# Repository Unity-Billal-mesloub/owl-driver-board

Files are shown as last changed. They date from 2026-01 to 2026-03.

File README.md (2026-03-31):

4-output OWL Driver Board version 2.4

4-output OWL Driver Board version 2.4

16-output OWL Driver Board version 1.0

16-output OWL Driver Board version 1.0
 
16-output OWL Driver Board version 1.0

The OWL Driver Board is a solid-state relay HAT for the Raspberry Pi. It was
developed for use with the [Open Weed Locator](https://github.com/Unity-Agriculture/OpenWeedLocator) 
but is suitable for any high-power, industrial, automotive or agricultural application.

It allows a Raspberry Pi to drive either 4x or 16x 2A outputs in any 12V or 24V
system, with the solid state switching allowing PWM control, including for
dimming LED strips. Outputs can be placed in parallel for more power if needed.

It is able to tolerate high levels of electrical noise, reverse polarity, short
circuit conditions and over voltage. It also protects the Pi from all this
electrical nastiness and provides a filtered source of 5V @ 5A!

It's ideal for use safely driving LED strips, high power motors, relays and
solenoids from a Raspberry Pi.

The board aims to be difficult to misconfigure and hard to damage.
Self-resetting polyfuses on the input and outputs limit current, and
TVS+Schottky diodes provide reverse polarity protection, protection against
noise and inductive voltage spikes, and over-voltage protection. This
protection also extends to communication buses with the Raspberry Pi.

# Features

### Both models (4x and 16x output versions)

* Open Hardware, made in the UK: schematics and design files freely available.
* Working voltage 7-26V
* 4x or 16x fused outputs, each max. 2A, high-side switched
* 1x e-stop / global enable input
* Outputs can be driven in multiple ways, configurable by a header
* From Raspberry PI GPIOs
* Directly from external control, via wires to a header. Control inputs are tolerant up to 26V.
* Buck converter generates 5.1V @ 3A continuous / 5A burst to power the Raspberry Pi (Pi 5 compatible!)
* Input and outputs are fused, with protection against over-voltage, reverse polarity, and inductive spikes
* LED indication of blown fuses

### Additional features for the 4x output version only

* 1x fused input max. 7A
* Self-resetting input polyfuse
* Integrated PCA9685 PWM driver allows optional PWM control via I2C, compatible with Adafruit PCA9675 Python libraries
* Input and output connectors use high-quality Phoenix Contact screw terminals
* Version 2.4

### Additional features for the 16x output version only

* 3x fused inputs max. 10A each (connect all inputs in parallel for 30A total board input power)
* 10A mini-blade fuses on inputs
* Spare fuse holder
* Inputs and outputs use JST VH connectors
* Version 1.0

# Purchase a finished board

You can buy a finished board (4x or 16x output versions) via the following distributors:

 * [paradar.co.uk](https://paradar.co.uk/products/owl-driver-board-raspberry-pi-automotive-relay-hat)

# Changelog

## 16x v1.1

* Correctly connect the input connectors to the input fuses.
* Add 10k discharge resistors across each output, to reduce "ghost voltages"
  see when outputs are off, caused by leakage across the MOSFETs

## 16x v1.0

* Initial prototype of a 16-output version of the PCB. Note the Gerbers for
  this version have a bug - the input connectors are not attached to the fuse
  input, and a link must be manually soldered.

## 4x v2.5

* Add 10k discharge resistors across each output, to reduce "ghost voltages"
  see when outputs are off, caused by leakage across the MOSFETs
* Change screw terminals for Phoenix Contact part 1935161 (C3819953), replaces 1890963. #1935161 is 11mm in height (down from 13mm) which improves clearance
  in the enclosure.

## 4x v2.4

* Add an "output enable" terminal (J10) for use with an emergency stop switch.
  Outputs are enabled when the terminal is shorted; they are disabled when it
  is disconnected.

## 4x v2.3

* Improved Pi regulator efficiency (81% -> 87%) to reduce heat generated when
  driving a Raspberry Pi 5

## 4x v2.2

* Change out the switching buck regulator from a 2A max limit to a 5A model.
  Increase the regulation voltage from 5.0V -> 5.1V to drive a Raspberry Pi 5
  without undervoltage warnings.
* Add a LM73100 ideal diode on the Pi 5V output to ensure there is no backflow
  of current from the Pi into the board when powered off, and the Pi has a
  separate USB-C power supply.

## 4x v2.1

* Add a slot for the Raspberry Pi camera connector, to allow the ribbon cable
  to easily pass through the driver board.
* Remove stacking power connector to allow space for the cable slot. If
  stacking is required, board power inputs should be wired in parallel.
* Fix major error in v2.0 where MOSFET rotations were incorrect
* General manufacturability improvements (component polarity in silkscreen)

## 4x v2.0

* Significantly rework layout to allow space for instructions on the top. Move
  most components to the bottom layer.
* Change MOSFETs from TO-220 to a compact SMD footprint.
* Add indicator LED to each output and the power input.
* Switch to generic spring connectors that are PTH rather than SMD; the Wago
  SMD connectors did not hold up well in use.
* Change diodes from SMA to DO-123F to save space.
* Change most resistors from 0805 to 0603 to save space.

## 4x v1.0

Initial prototype.

# Schematic and layout

KiCanvas links:

 * [Schematic](https://kicanvas.org/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)
 * [Layout](https://kicanvas.org/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)

# License

This open hardware project is Copyright (c) 2022 Guy Coleman and Patrick Coleman, and is released under an MIT license.

# Stacking

The HATs may be stacked and controlled with the PCA9685 by selecting different
I2C addresses for each board in the stack. In this configuation, the input power
terminals should be wired in parallel. Ensure that the wires used are rated for
sufficient current.

When stacked and in GPIO mode, turning on output #1 from the Raspberry Pi will
turn on all #1 outputs in the stack.

For individual control of all outputs in the stack
1. Set jumpers on header J6 to control outputs via the PCA9685 (the "PWM" setting).
1. Set SW1 to select a different address for each board in the stack.
1. Use the Adafruit PCA9685 Python library on the Raspberry Pi to communicate
   with each board via the chosen I2C addresses and control outputs
   individually.

Pi pin 22 (GPIO25) is connected to the PCA9685 Output Enable pin. Driving this
pin high on the Pi will disable all outputs in the stack (eg, for a software
emergency stop). It must be driven low for normal operation.

# Manufacturing

The project is set up for easy manufacture and assembly with JLCPCB, though it
will work with other suppliers too. All components should be available at
JLCPCB/LCSC and LCSC part numbers are included in KiKad fields for each part.

If you are having JLCPCB assemble the boards for you, you must manufacture in
panels (two boards per panel), as the board is too small for assembly alone. If
you will be assembling yourself, use pcb/gerbers/gb-owl-driver-board.zip for a single board.

1. Upload pcb/gerbers-panel-v2.4/gb-owl-driver-board-v2.4.zip to [JLCPCB's order tool](https://cart.jlcpcb.com/quote)
1. Configure the PCB manufacture settings to your requirements. Select "Confirm production file: Yes"
1. Select SMT assembly, and configure as follows: "Standard" assembly, "Both sides", and "Confirm production file". Click Confirm.
1. When prompted, upload the BOM (pcb/owl-driver-board_bom_jlc.csv) and Component Placement/CPL (pcb/owl-driver-board_cpl_jlc.csv) files.
1. Complete the SMT assembly wizard, aligning the parts to the board if necessary.

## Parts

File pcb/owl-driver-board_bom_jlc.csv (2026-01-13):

Comment | Designator | Footprint | LCSC Part Number
10uF | C1,C2,C3,C4,C5,C10,C11,C12,C14,C15,C16,C18,C19,C20 | C_1206_3216Metric_nosilk | C89835
0.1uF | C6,C7,C9,C17,C21,C25,C26,C27,C28,C29,C30 | C_0603_1608Metric_nosilk | C14663
100uF 6.3V | C13 | CP_EIA-3528-21_Kemet-B | C16133
10p | C22 | C_0805_2012Metric | C107107
2n | C23 | C_0603_1608Metric_nosilk | C1870141
10n | C24 | C_0603_1608Metric_nosilk | C77053
SZYY0805R | D1,D4,D5,D19,D20 | LED_0805_2012Metric | C434431
BZT585B13T-7 13V | D2,D3,D6,D17,D18 | D_SOD-523_silkpolarity | C460799
SMBJ26A | D7 | D_SMB_silkpolarity | C315992
DSK34 | D8,D9,D10,D11,D12,D13,D21,D22,D23,D24,D25,D26,D40 | D_SOD-123F_silkpolarity | C727076
SMBJ5.0A | D16 | D_SMB_silkpolarity | C83333
SZYY0805YG | D29,D30,D31,D37,D38,D41 | LED_0805_2012Metric | C434435
AZ23C3V3 | D32,D33,D34,D35 | SOT-23_nosilk | C968007
PDS1040L-13 | D36 | D_PowerDI-5 | C154714
BZT52C5V1T | D39,D42,D43,D44,D45 | D_SOD-523_silkpolarity | C2987034
2920L700/12 | F1 | Fuse_2920_7451Metric_nosilk | C207092
2920L200DR | F2,F3,F4,F5 | Fuse_2920_7451Metric_nosilk | C207087
CONN_04 | J1 | 1X04_NO_SILK | C358686
RASPBERRYPI-40-PIN-GPIO | J2 | Pin_Header_Straight_2x20 | C35165
1935161 | J3,J4,J5,J7,J8,J10 | TerminalBlock_Phoenix_PT-1,5-2-5.0-H_1x02_P5.00mm_Horizontal | C3819953
CONN_04X2 | J6 | 2X4 | C358693
PI 5V | J9 | PinHeader_1x02_P2.54mm_Vertical_nosilk | C358684
ENABLE | J11 | PinHeader_1x02_P2.54mm_Vertical_nosilk | C358684
10uH | L1 | L_10.4x10.4_H4.8 | C7461391
AGM60P85AP | Q1,Q2,Q3,Q6,Q7 | PDFN-8-3.3x3.3 | C17701049
2N7002 | Q4,Q5,Q8,Q9 | SOT-23_nosilk | C8545
1k | R1,R2,R3,R4,R5,R9,R10,R13,R14,R15,R16,R19,R20,R23,R39,R40,R48,R49 | R_0603_1608Metric | C21190
470 | R6,R7,R17,R18,R24,R25,R26,R27,R29,R30,R31,R38,R54,R55,R56,R57,R58 | R_0603_1608Metric | C25241
10k | R8,R11,R12,R21,R22,R28,R32,R33,R34,R35,R36,R37,R47,R50,R51,R52,R53,R59,R60,R61,R62 | R_0603_1608Metric | C15401
165k | R41 | R_0603_1608Metric | C22816
10.2k | R42 | R_0603_1608Metric | C22772
43k | R43 | R_0603_1608Metric | C23172
14k | R44 | R_0603_1608Metric | C22803
1.87k | R45 | R_0603_1608Metric | C22850
360k | R46 | R_0603_1608Metric | C23146
SW_Coded_SH-7050 | SW1 | Diptronics-Rotary-Switch-R7M3-16RA-V | C501563
TPS54531DDA | U1 | Texas_R-PDSO-G8_EP2.95x4.9mm_Mask2.4x3.1mm_ThermalVias | C50605
PCA9685PW | U2 | TSSOP-28_4.4x9.7mm_P0.65mm | C2678753
LM73100 | U3 | LM73100-QFN10 | C3210761
74LVC1G08 | U4,U5,U6,U7,U8 | SOT-353_SC-70-5 | C12512
XC6206P332MR | U9 | SOT-23 | C5148692

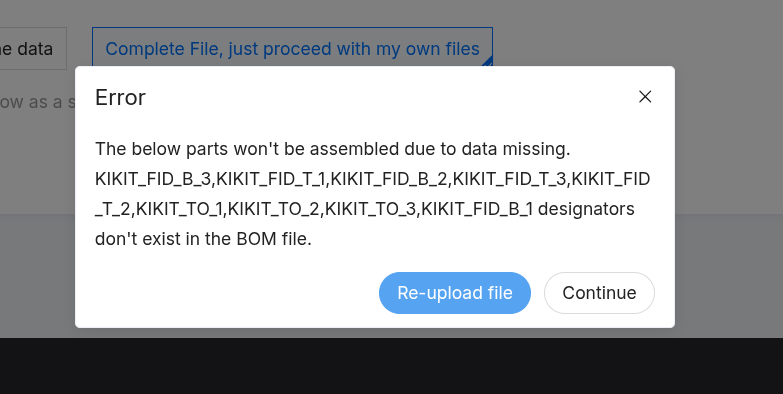
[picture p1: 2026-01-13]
doc/ordering-4-jlcpcb-ignore-this-error.png

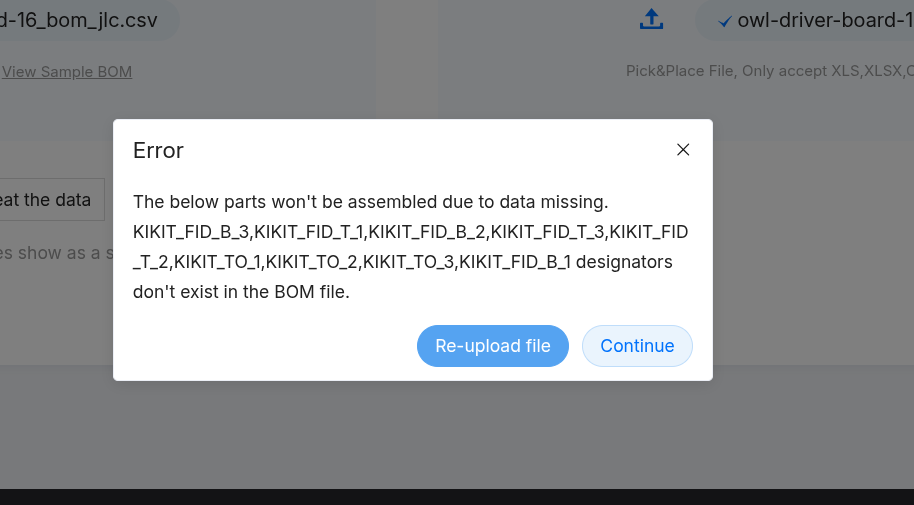
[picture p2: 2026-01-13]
doc/ordering-16-jlcpcb-ignore-this-error.png

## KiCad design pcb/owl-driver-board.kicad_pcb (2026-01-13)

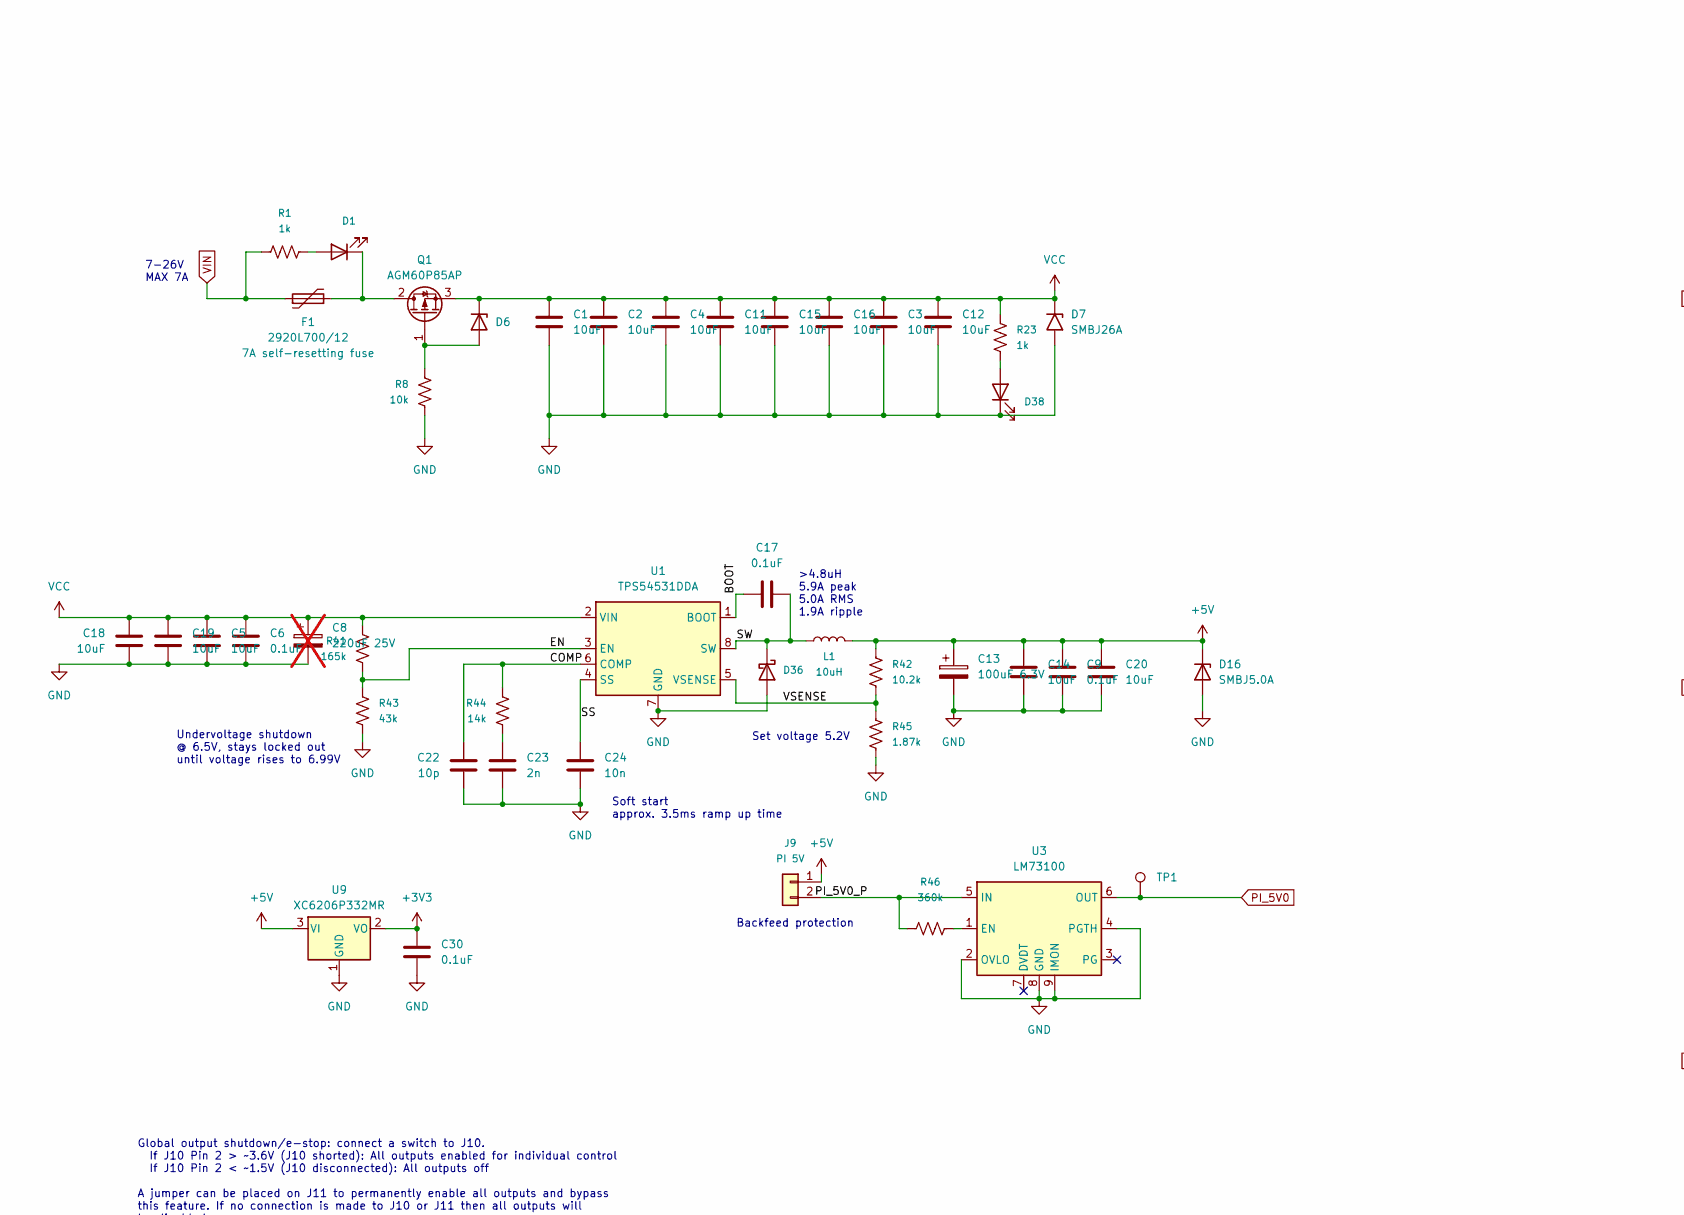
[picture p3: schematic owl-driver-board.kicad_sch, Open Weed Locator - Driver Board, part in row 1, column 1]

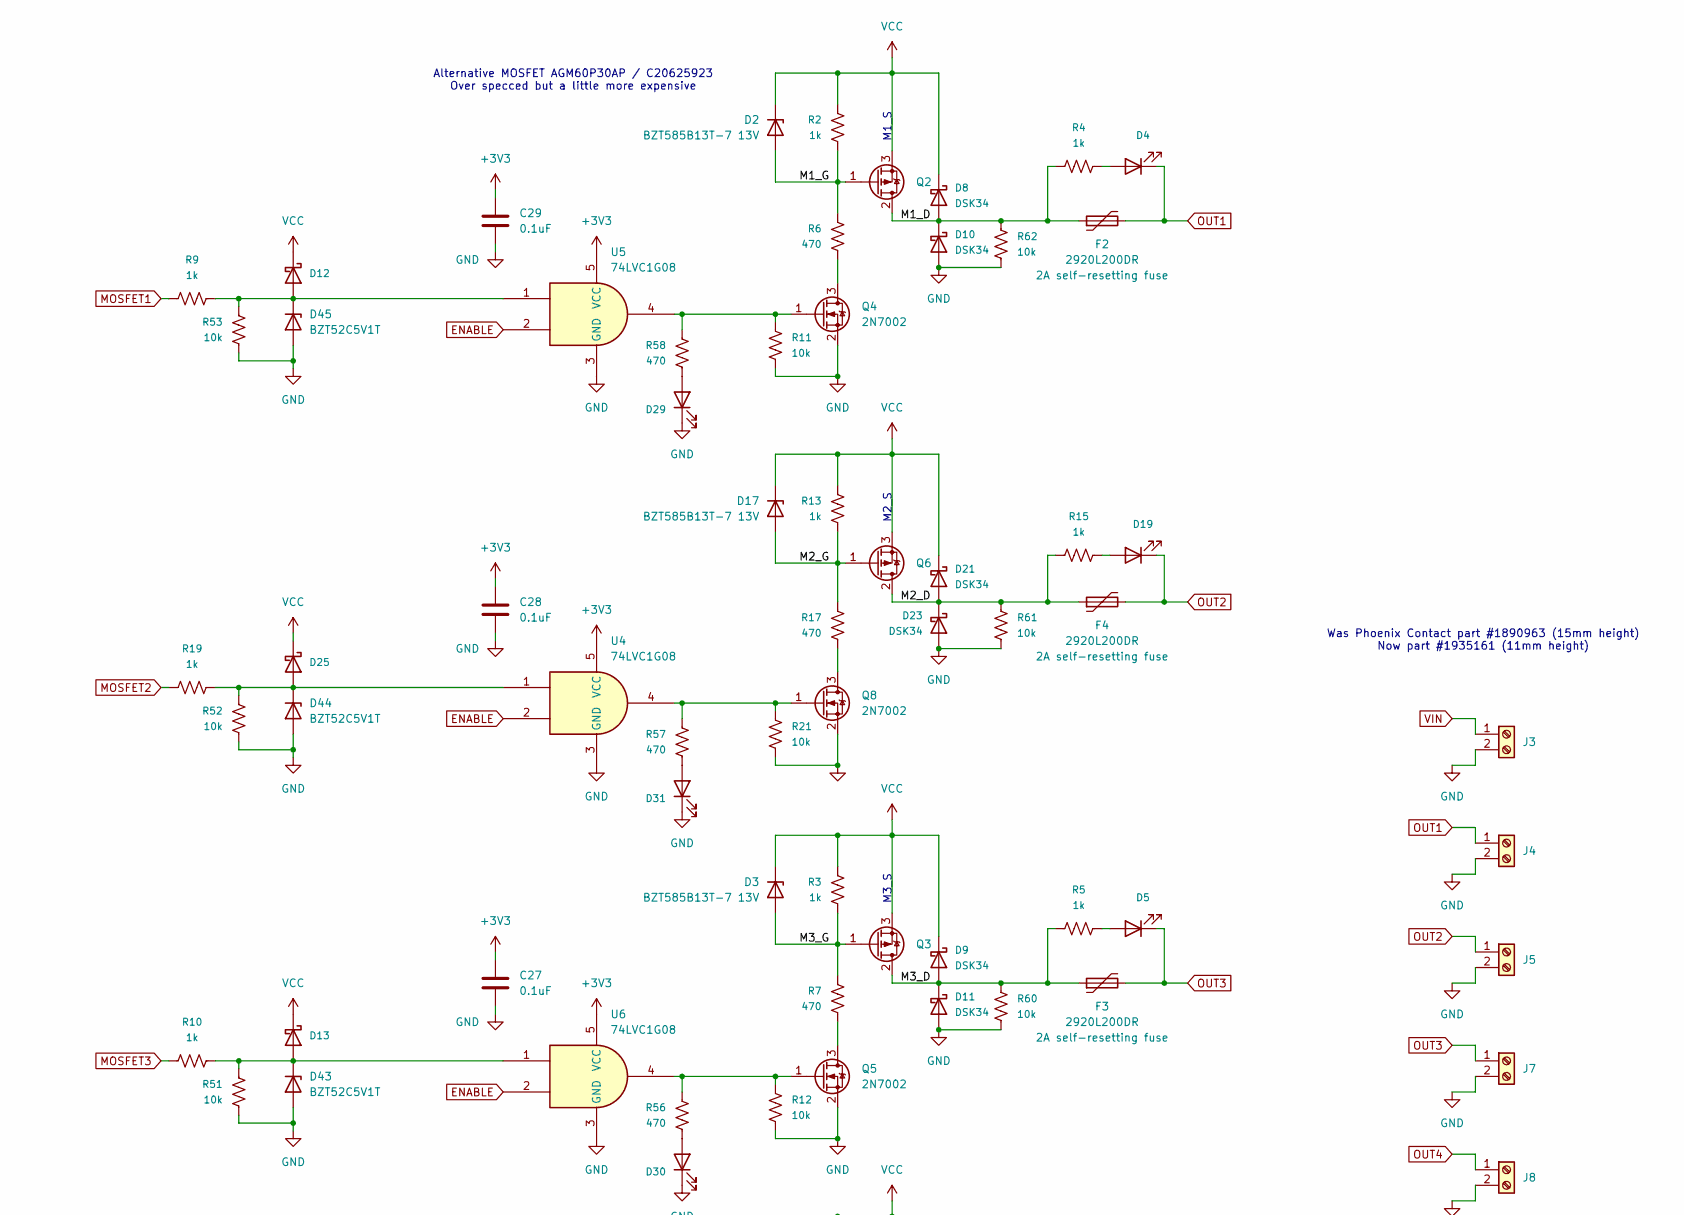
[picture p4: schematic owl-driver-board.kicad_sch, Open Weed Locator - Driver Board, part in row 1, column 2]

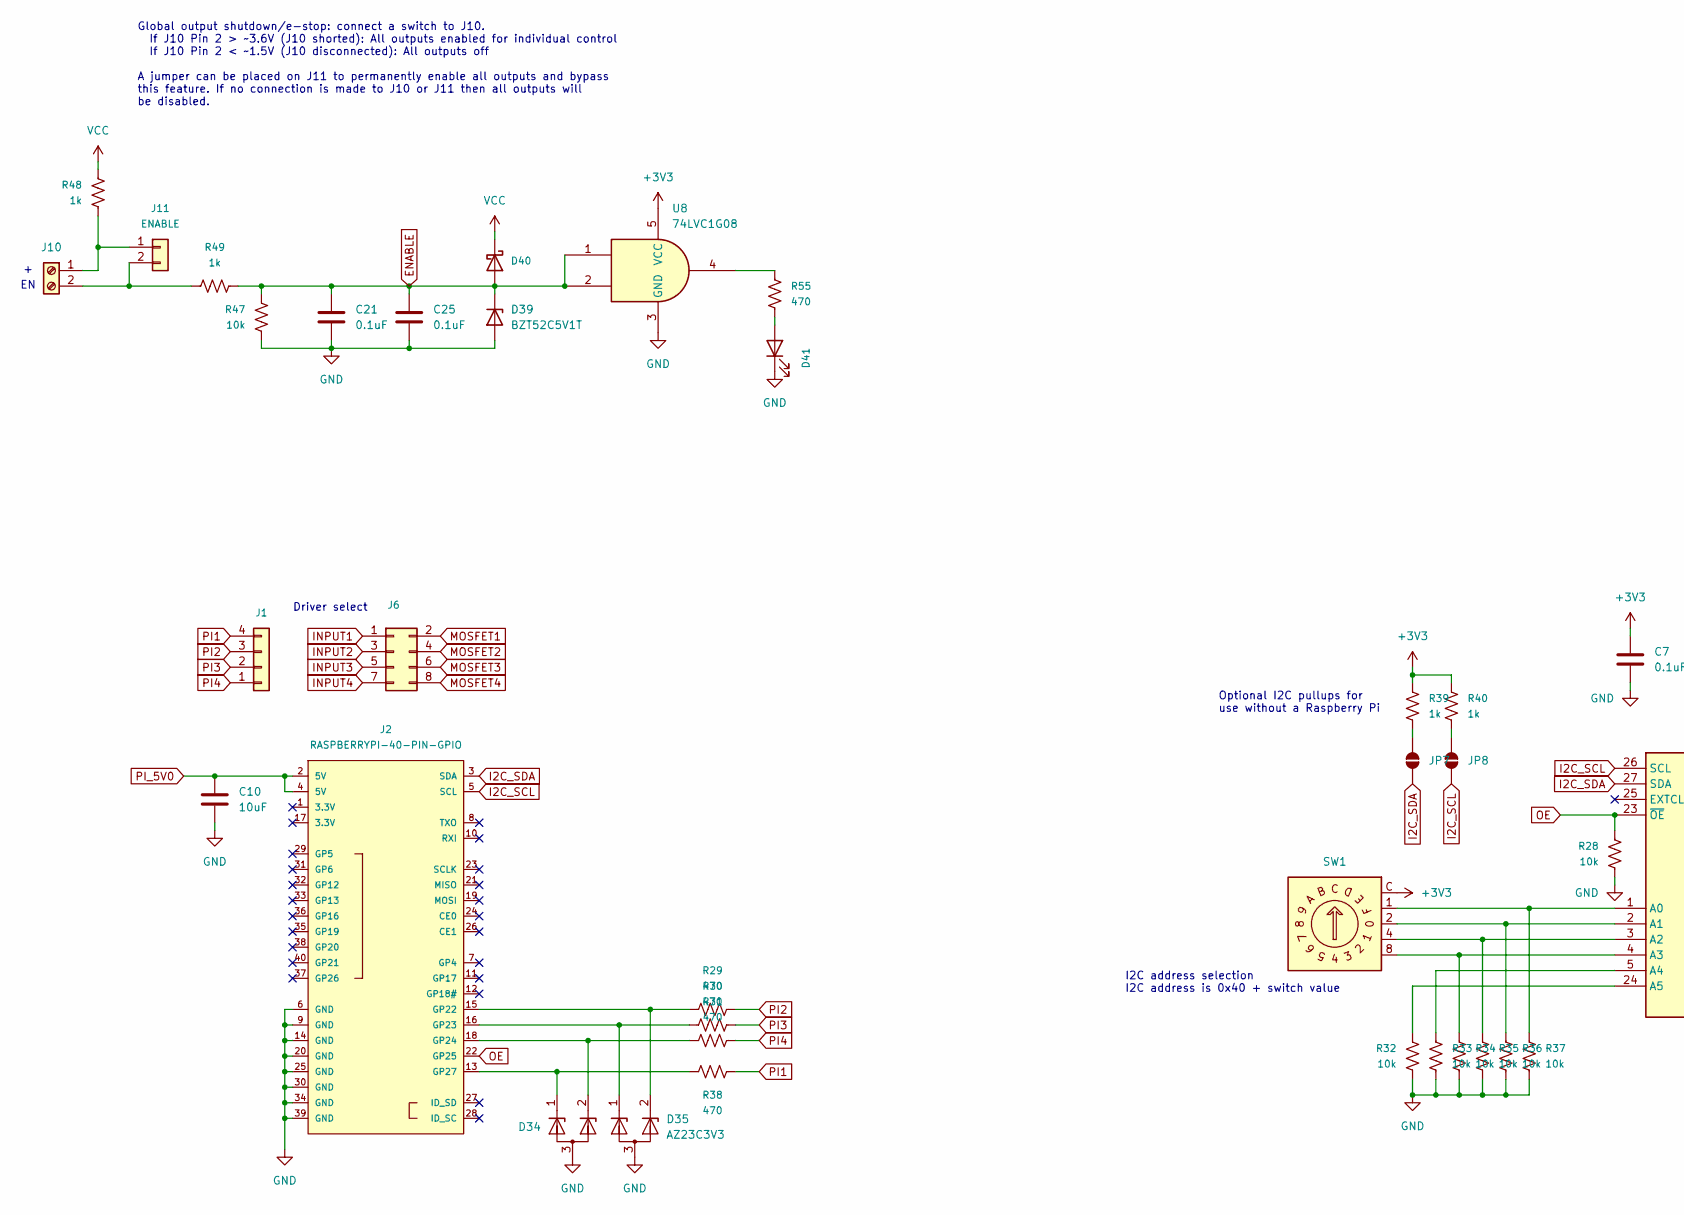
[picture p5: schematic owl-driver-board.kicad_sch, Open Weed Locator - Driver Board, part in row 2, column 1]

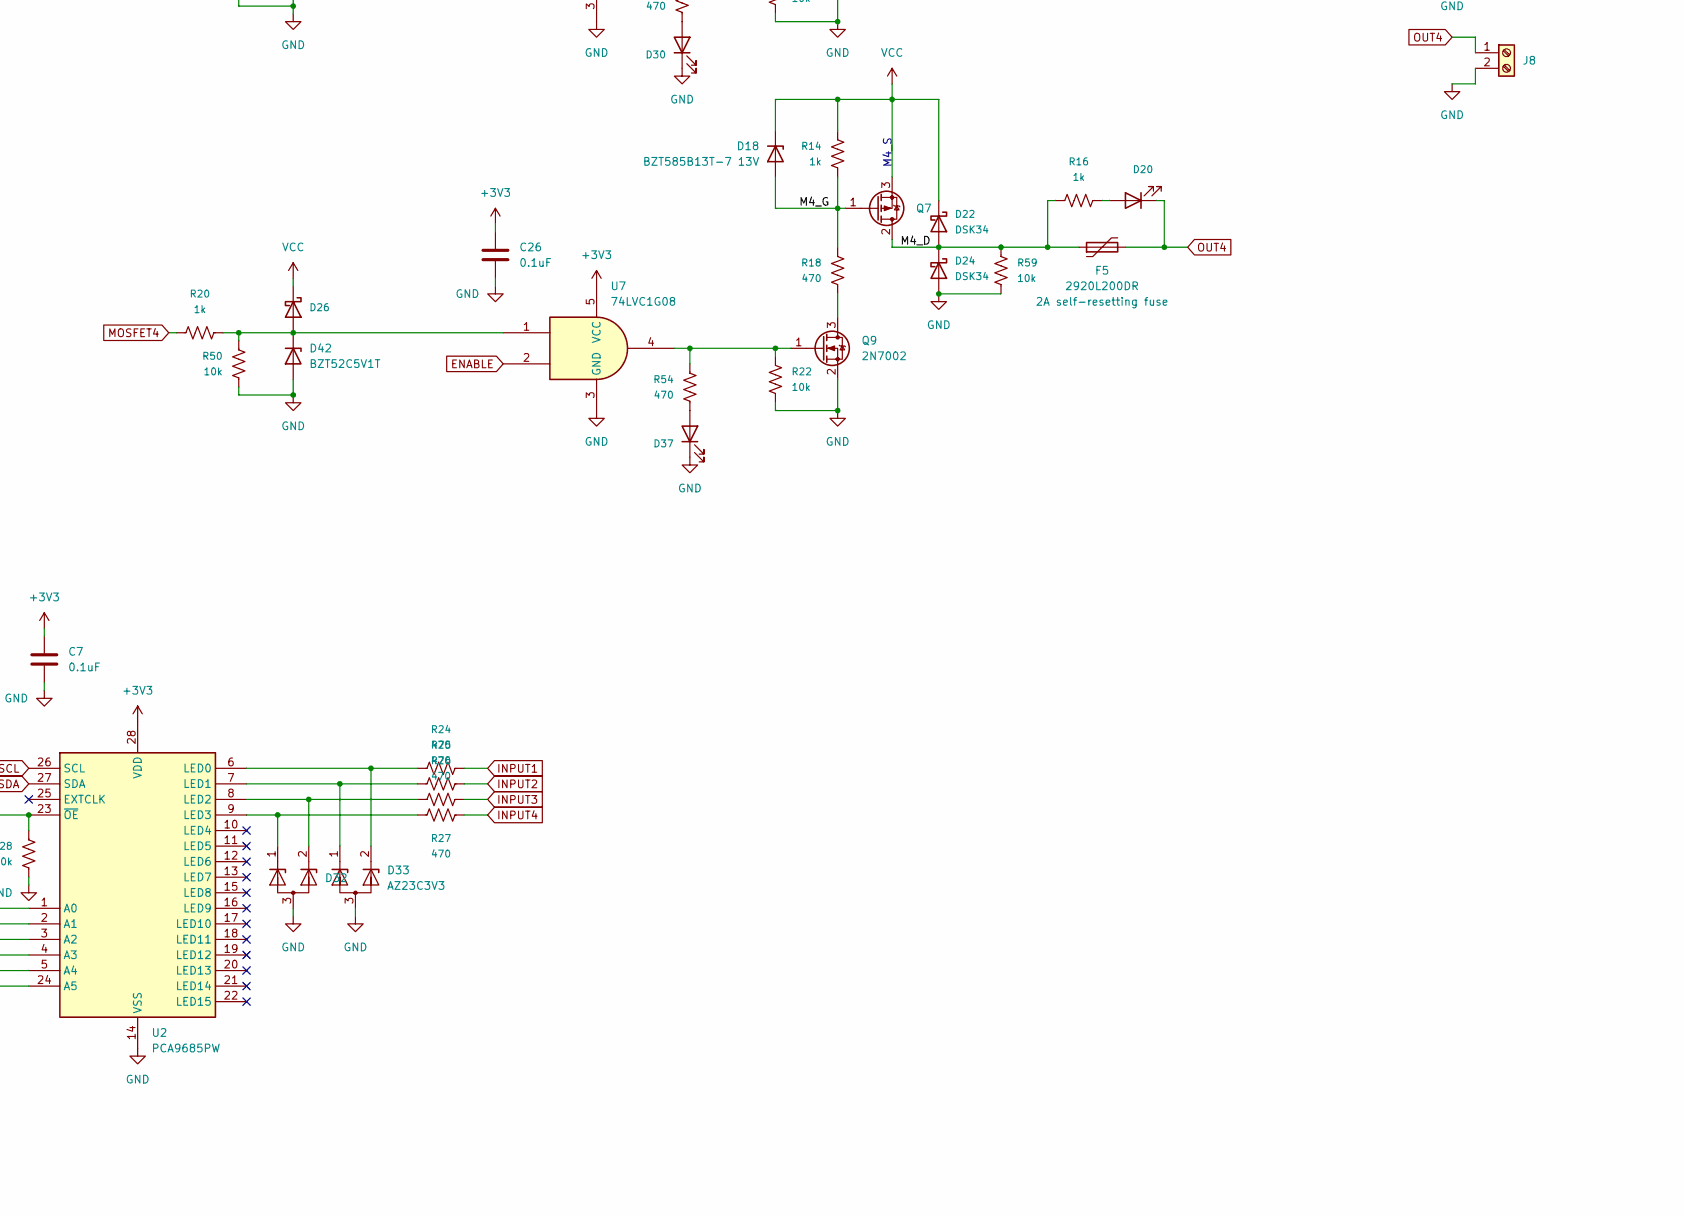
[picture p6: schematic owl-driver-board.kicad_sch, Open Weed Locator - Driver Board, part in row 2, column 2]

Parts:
C1, C2, C3, C4, C5, C10, C11, C12, C14, C15, C16, C18, C19, C20: 10uF; C_1206_3216Metric_nosilk; Part 1206X106K500CT; LCSC C89835
C6, C7, C9, C17, C21, C25, C26, C27, C28, C29, C30: 0.1uF; C_0603_1608Metric_nosilk; LCSC C14663
C8: 220uF 25V; CP_Radial_D8.0mm_P3.50mm; LCSC C216322; not fitted
C13: 100uF 6.3V; CP_EIA-3528-21_Kemet-B; LCSC C16133
C22: 10p; C_0805_2012Metric; Part CC0805JRNPO9BN100; LCSC C107107
C23: 2n; C_0603_1608Metric_nosilk; Part GCM1885C1H202FA16J; LCSC C1870141
C24: 10n; C_0603_1608Metric_nosilk; Part GRM188R71H103KA01D; LCSC C77053
D1, D4, D5, D19, D20: SZYY0805R; LED_0805_2012Metric; LCSC C434431
D2, D3, D6, D17, D18: BZT585B13T-7 13V; D_SOD-523_silkpolarity; Part BZT585B13T-7; LCSC C460799
D7: SMBJ26A; D_SMB_silkpolarity; LCSC C315992
D8, D9, D10, D11, D12, D13, D21, D22, D23, D24, D25, D26, D40: DSK34; D_SOD-123F_silkpolarity; LCSC C727076
D16: SMBJ5.0A; D_SMB_silkpolarity; LCSC C83333
D29, D30, D31, D37, D38, D41: SZYY0805YG; LED_0805_2012Metric; LCSC C434435
D32, D33, D34, D35: AZ23C3V3; SOT-23_nosilk; LCSC C968007
D36: PDS1040L-13; D_PowerDI-5; Part PDS1040L-13; LCSC C154714
D39, D42, D43, D44, D45: BZT52C5V1T; D_SOD-523_silkpolarity; LCSC C2987034
F1: 2920L700/12; Fuse_2920_7451Metric_nosilk; LCSC C207092
F2, F3, F4, F5: 2920L200DR; Fuse_2920_7451Metric_nosilk; LCSC C207087
J1: CONN_04; 1X04_NO_SILK; LCSC C358686
J2: RASPBERRYPI-40-PIN-GPIO; Pin_Header_Straight_2x20; LCSC C35165
J3, J4, J5, J7, J8, J10: 1935161; TerminalBlock_Phoenix_PT-1,5-2-5.0-H_1x02_P5.00mm_Horizontal; Part 1935161; LCSC C3819953
J6: CONN_04X2; 2X4; LCSC C358693
J9: PI 5V; PinHeader_1x02_P2.54mm_Vertical_nosilk; LCSC C358684
J11: ENABLE; PinHeader_1x02_P2.54mm_Vertical_nosilk; LCSC C358684
JP7, JP8: A0; SolderJumper-2_P1.3mm_Open_RoundedPad1.0x1.5mm_nosilk
L1: 10uH; L_10.4x10.4_H4.8; Part CXP1050-100M-AG(10uh); LCSC C7461391
Q1, Q2, Q3, Q6, Q7: AGM60P85AP; PDFN-8-3.3x3.3; LCSC C17701049
Q4, Q5, Q8, Q9: 2N7002; SOT-23_nosilk; LCSC C8545
R1, R2, R3, R4, R5, R9, R10, R13, R14, R15, R16, R19, R20, R23, R39, R40, R48, R49: 1k; R_0603_1608Metric; LCSC C21190
R6, R7, R17, R18, R24, R25, R26, R27, R29, R30, R31, R38, R54, R55, R56, R57, R58: 470; R_0603_1608Metric; LCSC C25241
R8, R11, R12, R21, R22, R28, R32, R33, R34, R35, R36, R37, R47, R50, R51, R52, R53, R59, R60, R61, R62: 10k; R_0603_1608Metric; LCSC C15401
R41: 165k; R_0603_1608Metric; Part 0603WAF1653T5E; LCSC C22816
R42: 10.2k; R_0603_1608Metric; Part 0603WAF1022T5E; LCSC C22772
R43: 43k; R_0603_1608Metric; Part 0603WAF4302T5E; LCSC C23172
R44: 14k; R_0603_1608Metric; Part 0603WAF1402T5E; LCSC C22803
R45: 1.87k; R_0603_1608Metric; Part 0603WAF1871T5E; LCSC C22850
R46: 360k; R_0603_1608Metric; Part 0603WAF3603T5E; LCSC C23146
SW1: SW_Coded_SH-7050; Diptronics-Rotary-Switch-R7M3-16RA-V; Part R7M3-16RA-V-T/R; LCSC C501563
TP1: TestPoint; TestPoint_Pad_D1.5mm_NoSilk
U1: TPS54531DDA; Texas_R-PDSO-G8_EP2.95x4.9mm_Mask2.4x3.1mm_ThermalVias; Part TPS54531DDAR; LCSC C50605
U2: PCA9685PW; TSSOP-28_4.4x9.7mm_P0.65mm; LCSC C2678753
U3: LM73100; LM73100-QFN10; Part LM73100RPWR; LCSC C3210761
U4, U5, U6, U7, U8: 74LVC1G08; SOT-353_SC-70-5; Part 74LVC1G08GW,125; LCSC C12512
U9: XC6206P332MR; SOT-23; Part XC6206P332MR; LCSC C5148692

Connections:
+3V3: C7.1, C26.1, C27.1, C28.1, C29.1, C30.1, R39.2, R40.2, SW1.C, U2.28 (VDD), U4.5 (VCC), U5.5 (VCC), U6.5 (VCC), U7.5 (VCC), U8.5 (VCC), U9.2 (VO)
+5V: C9.1, C13.1, C14.1, C20.1, D16.1 (K), J9.1, L1.2, R42.2, U9.3 (VI)
/BOOT: C17.1, U1.1 (BOOT)
/COMP: C22.1, R44.1, U1.6 (COMP)
/EN: R41.1, R43.2, U1.3 (EN)
/M1_D: D8.2 (A), D10.1 (K), F2.1, Q2.2 (D), R4.2, R62.2
/M1_G: D2.2 (A), Q2.1 (G), R2.1, R6.2
/M2_D: D21.2 (A), D23.1 (K), F4.1, Q6.2 (D), R15.2, R61.2
/M2_G: D17.2 (A), Q6.1 (G), R13.1, R17.2
/M3_D: D9.2 (A), D11.1 (K), F3.1, Q3.2 (D), R5.2, R60.2
/M3_G: D3.2 (A), Q3.1 (G), R3.1, R7.2
/M4_D: D22.2 (A), D24.1 (K), F5.1, Q7.2 (D), R16.1, R59.2
/M4_G: D18.2 (A), Q7.1 (G), R14.1, R18.2
/PI_5V0_P: J9.2, R46.2, U3.5 (IN)
/SS: C24.1, U1.4 (SS)
/SW: C17.2, D36.1 (K), L1.1, U1.8 (SW)
/VSENSE: R42.1, R45.2, U1.5 (VSENSE)
ENABLE: C21.1, C25.1, D39.1 (K), D40.2 (A), R47.1, R49.2, U4.2, U5.2, U6.2, U7.2, U8.1, U8.2
GND: C1.2, C2.2, C3.2, C4.2, C5.2, C6.2, C7.2, C8.2, C9.2, C10.2, C11.2, C12.2, C13.2, C14.2, C15.2, C16.2, C18.2, C19.2, C20.2, C21.2, C22.2, C23.2, C24.2, C25.2, C26.2, C27.2, C28.2, C29.2, C30.2, D7.2 (A2), D10.2 (A), D11.2 (A), D16.2 (A), D23.2 (A), D24.2 (A), D29.1 (K), D30.1 (K), D31.1 (K), D32.3 (A), D33.3 (A), D34.3 (A), D35.3 (A), D36.2 (A), D37.1 (K), D38.1 (K), D39.2 (A), D41.1 (K), D42.2 (A), D43.2 (A), D44.2 (A), D45.2 (A), J2.6 (GND), J2.9 (GND), J2.14 (GND), J2.20 (GND), J2.25 (GND), J2.30 (GND), J2.34 (GND), J2.39 (GND), J3.2, J4.2, J5.2, J7.2, J8.2, Q4.2 (S), Q5.2 (S), Q8.2 (S), Q9.2 (S), R8.1, R11.1, R12.1, R21.1, R22.1, R28.1, R32.1, R33.1, R34.1, R35.1, R36.1, R37.1, R43.1, R45.1, R47.2, R50.1, R51.1, R52.1, R53.1, R59.1, R60.1, R61.1, R62.1, U1.7 (GND), U1.9 (GND), U2.14 (VSS), U3.2 (OVLO), U3.4 (PGTH), U3.8 (GND), U3.9 (IMON), U4.3 (GND), U5.3 (GND), U6.3 (GND), U7.3 (GND), U8.3 (GND), U9.1 (GND)
I2C_SCL: J2.5 (SCL), JP8.1 (A), U2.26 (SCL)
I2C_SDA: J2.3 (SDA), JP7.1 (A), U2.27 (SDA)
INPUT1: J6.1, R24.2
INPUT2: J6.3, R25.2
INPUT3: J6.5, R26.2
INPUT4: J6.7, R27.2
MOSFET1: J6.2, R9.2
MOSFET2: J6.4, R19.2
MOSFET3: J6.6, R10.2
MOSFET4: J6.8, R20.2
unnamed: C23.1, R44.2
unnamed: D1.2 (A), R1.1
unnamed: D1.1 (K), F1.2, Q1.2 (D)
unnamed: D4.2 (A), R4.1
unnamed: D5.2 (A), R5.1
unnamed: D6.2 (A), Q1.1 (G), R8.2
unnamed: D12.2 (A), D45.1 (K), R9.1, R53.2, U5.1
unnamed: D13.2 (A), D43.1 (K), R10.1, R51.2, U6.1
unnamed: D19.2 (A), R15.1
unnamed: D20.2 (A), R16.2
unnamed: D25.2 (A), D44.1 (K), R19.1, R52.2, U4.1
unnamed: D26.2 (A), D42.1 (K), R20.1, R50.2, U7.1
unnamed: D29.2 (A), R58.1
unnamed: D30.2 (A), R56.1
unnamed: D31.2 (A), R57.1
unnamed: D37.2 (A), R54.1
unnamed: D38.2 (A), R23.1
unnamed: D41.2 (A), R55.1
unnamed: D35.2 (K), J2.15 (GP22), R29.1
unnamed: D35.1 (K), J2.16 (GP23), R30.1
unnamed: D34.2 (K), J2.18 (GP24), R31.1
unnamed: D34.1 (K), J2.13 (GP27), R38.1
unnamed: J10.1, J11.1, R48.2
unnamed: J10.2, J11.2, R49.1
unnamed: JP7.2 (B), R39.1
unnamed: JP8.2 (B), R40.1
unnamed: Q4.3 (D), R6.1
unnamed: Q4.1 (G), R11.2, R58.2, U5.4
unnamed: Q5.3 (D), R7.1
unnamed: Q5.1 (G), R12.2, R56.2, U6.4
unnamed: Q8.3 (D), R17.1
unnamed: Q8.1 (G), R21.2, R57.2, U4.4
unnamed: Q9.3 (D), R18.1
unnamed: Q9.1 (G), R22.2, R54.2, U7.4
unnamed: R55.2, U8.4
unnamed: R37.2, SW1.1, U2.1 (A0)
unnamed: R36.2, SW1.2, U2.2 (A1)
unnamed: R35.2, SW1.4, U2.3 (A2)
unnamed: R34.2, SW1.8, U2.4 (A3)
unnamed: R33.2, U2.5 (A4)
unnamed: R32.2, U2.24 (A5)
unnamed: D33.2 (K), R24.1, U2.6 (LED0)
unnamed: D33.1 (K), R25.1, U2.7 (LED1)
unnamed: D32.2 (K), R26.1, U2.8 (LED2)
unnamed: D32.1 (K), R27.1, U2.9 (LED3)
unnamed: R46.1, U3.1 (EN)
OE: J2.22 (GP25), R28.2, U2.23 (~OE)
OUT1: D4.1 (K), F2.2, J4.1
OUT2: D19.1 (K), F4.2, J5.1
OUT3: D5.1 (K), F3.2, J7.1
OUT4: D20.1 (K), F5.2, J8.1
PI1: J1.4, R38.2
PI2: J1.3, R29.2
PI3: J1.2, R30.2
PI4: J1.1, R31.2
PI_5V0: C10.1, J2.2 (5V), J2.4 (5V), TP1.1, U3.6 (OUT)
VCC: C1.1, C2.1, C3.1, C4.1, C5.1, C6.1, C8.1, C11.1, C12.1, C15.1, C16.1, C18.1, C19.1, D2.1 (K), D3.1 (K), D6.1 (K), D7.1 (A1), D8.1 (K), D9.1 (K), D12.1 (K), D13.1 (K), D17.1 (K), D18.1 (K), D21.1 (K), D22.1 (K), D25.1 (K), D26.1 (K), D40.1 (K), Q1.3 (S), Q2.3 (S), Q3.3 (S), Q6.3 (S), Q7.3 (S), R2.2, R3.2, R13.2, R14.2, R23.2, R41.2, R48.1, U1.2 (VIN)
VIN: F1.1, J3.1, R1.2

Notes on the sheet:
I2C address selection I2C address is 0x40 + switch value
M2_S
Undervoltage shutdown @ 6.5V, stays locked out until voltage rises to 6.99V
Backfeed protection
M4_S
Driver select
Optional I2C pullups for use without a Raspberry Pi
Soft start approx. 3.5ms ramp up time
>4.8uH 5.9A peak 5.0A RMS 1.9A ripple
Set voltage 5.2V
Alternative MOSFET AGM60P30AP / C20625923 Over specced but a little more expensive
Global output shutdown/e-stop: connect a switch to J10. If J10 Pin 2 > ~3.6V (J10 shorted): All outputs enabled for individual control If J10 Pin 2 < ~1.5V (J10 disconnected): All outputs off A jumper can be placed on J11 to permanently enable all outputs and bypass this feature. If no connection i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
M3_S
M1_S
7-26V MAX 7A
Was Phoenix Contact part #1890963 (15mm height) Now part #1935161 (11mm height)

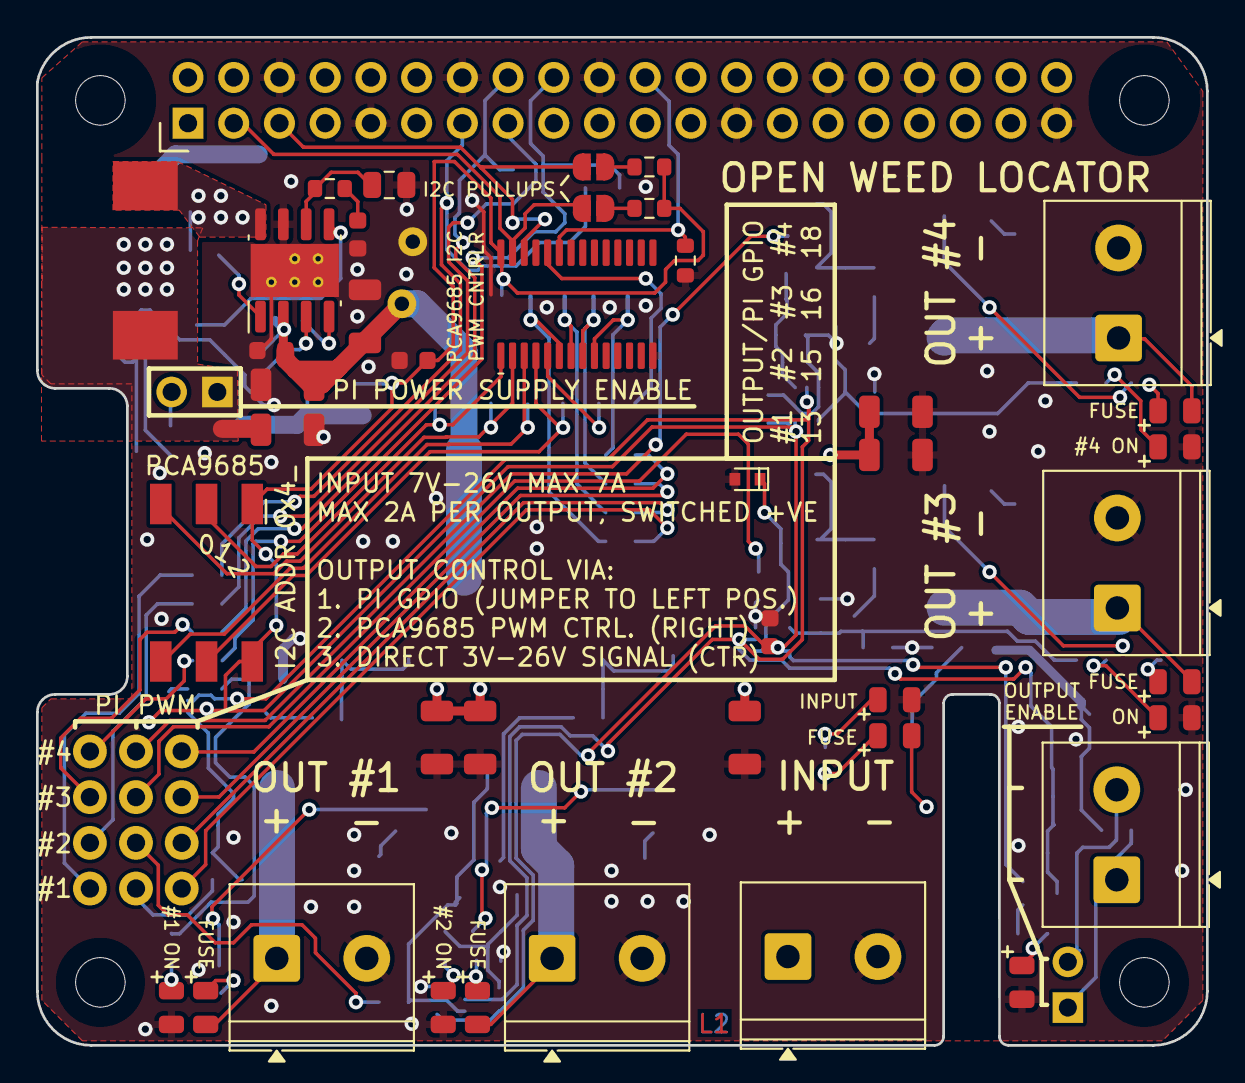
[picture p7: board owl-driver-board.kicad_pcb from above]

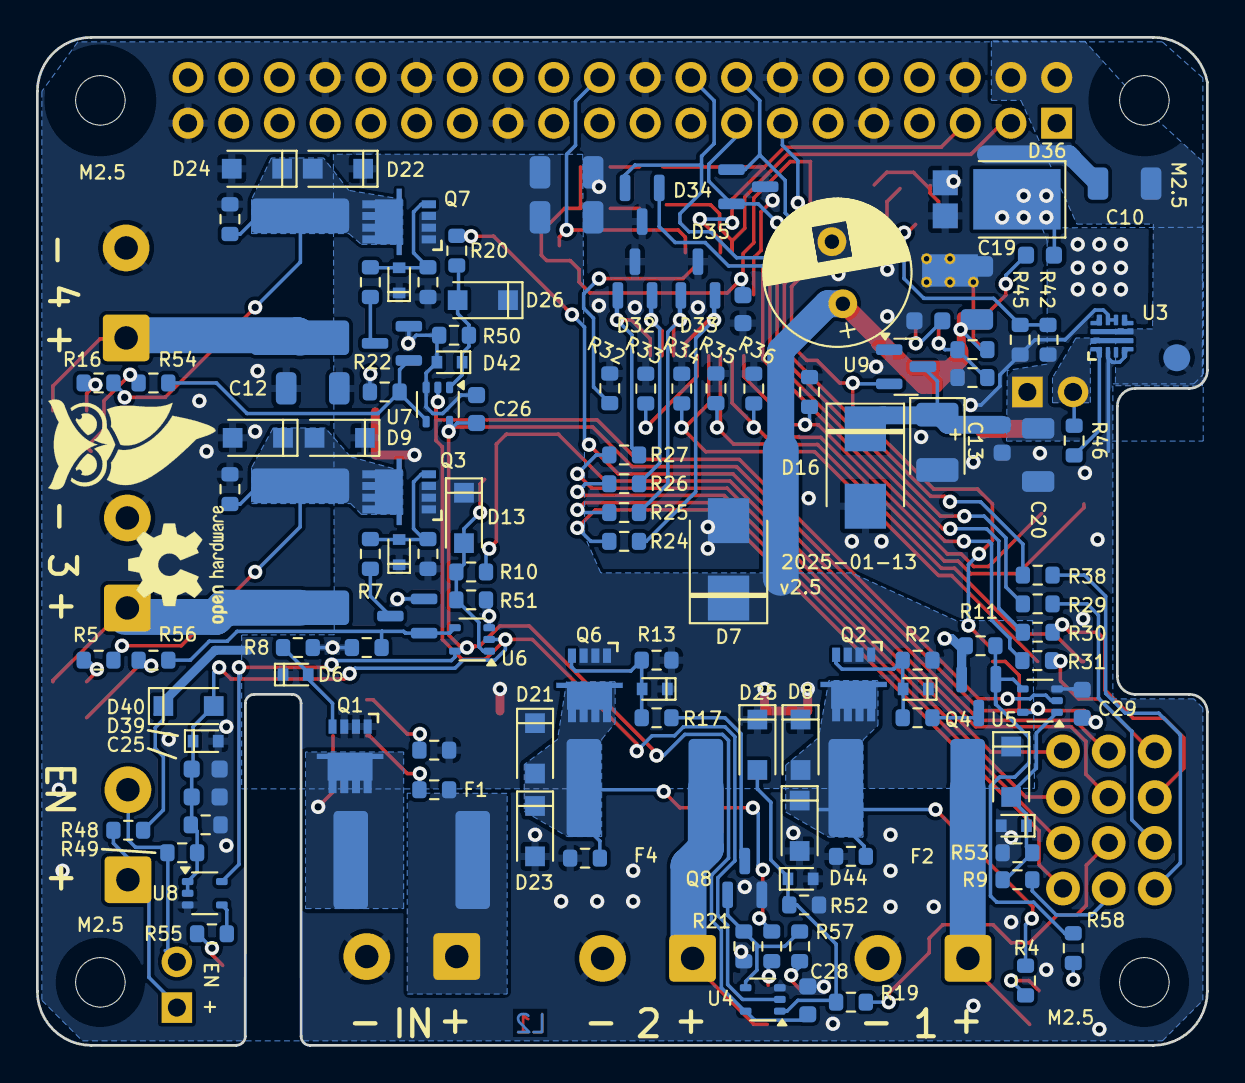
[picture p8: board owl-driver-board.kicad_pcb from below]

Board: 2 copper layers, 65.0 x 56.0 mm, 181 parts (127 on the bottom side), 87 nets.

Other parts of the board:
LOGO1: OSHW-Logo2_7.3x6mm_SilkScreen
PI1, PI2, PI3, PI4: RPi_Hat_Mounting_Hole
TAB1, TAB2, TAB3, TAB4: Tab

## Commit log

2026-01-13 add 16-way board v1.1, with additional discharge resistor across outputs
    [output_chain.kicad_sch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]
2026-01-13 4-way board, revision v2.5
    Bump the revision with some small tweaks -
    - Lower profile Phoenix Contact screw terminals - replace 1890963 with 1935161 (C3819953)
    - 10k discharge resistor across all outputs to reduce ghost voltages
    - Format updates for KiCad 9
    [owl-driver-board.kicad_pcb, owl-driver-board.kicad_sch, owl-driver-board_bom_jlc.csv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]
